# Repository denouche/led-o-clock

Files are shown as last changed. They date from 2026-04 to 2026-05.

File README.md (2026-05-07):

# Led'o'clock

> 🚧 WORK IN PROGRESS: This project is currently under active development. Files and documentation may change frequently.

Led'o'clock is a smart, connected, visual nightlight and time indicator designed to help kids understand when it's time to sleep, play, or wake up. 

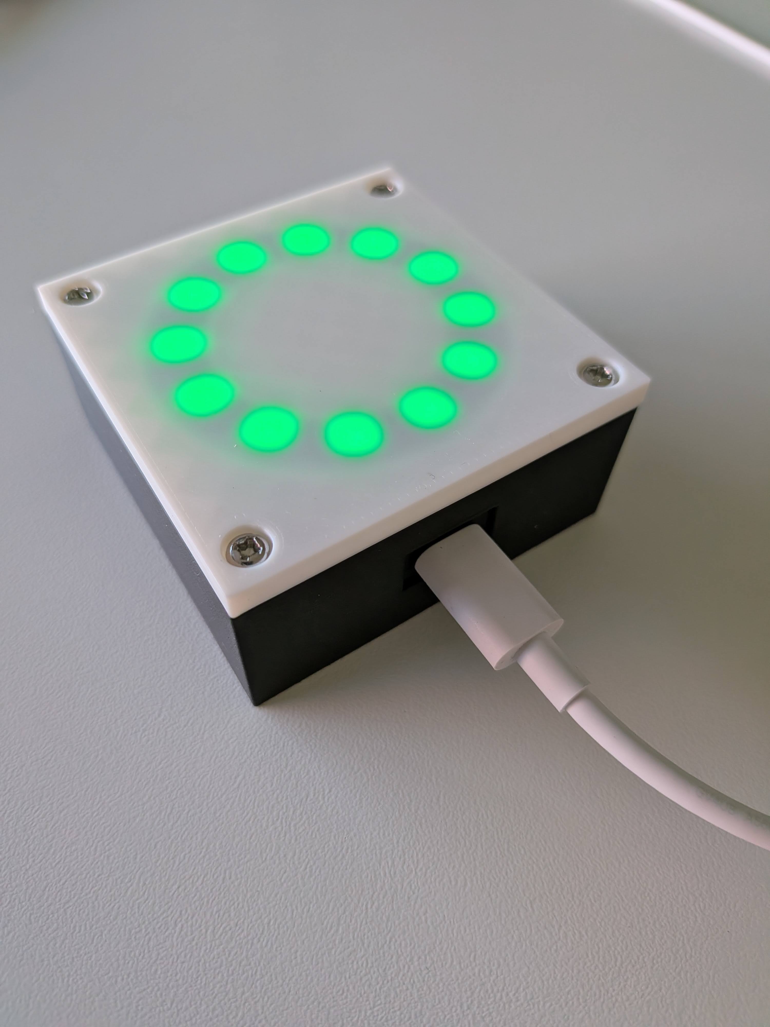
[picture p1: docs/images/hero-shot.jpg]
Led'o'clock fully assembled


This monorepo contains everything you need to build your own: the custom PCB, the 3D printable enclosure, and the ESP32 firmware.

## Usage

### LED Color Code

During normal operation, the ring displays the color defined in the active time slot of your schedule.

> Note that if no schedule is set, the ring will remain off. It's the initial state after configuring WiFi.

The LED ring also provides visual feedback for system events:

| Color | Meaning |
| :--- | :--- |
| 🔵 Light Blue | Device is booting and connecting to WiFi. |
| 🟡 Yellow | WiFi configuration mode — Access Point active. |
| 🟢 Green (×5 blinks) | WiFi connection successful. |
| 🟣 Purple | OTA firmware update in progress. |
| 🔴 Red (×5 blinks) | Factory Reset in progress. |

### Factory Reset

To reset the device to factory settings (wipes WiFi credentials and all configuration):

1. Hold the button on the back of the device for **5 seconds**.
2. The LED ring will start **blinking red** to confirm the reset is in progress.
3. The device restarts in Access Point mode, ready to be reconfigured.

## Features

* **Visual Time Tracking:** Uses a WS2812B LED ring to display specific colors based on the time of day.
* **Progressive Countdown:** LEDs turn off one by one to visually show how much time is left before the next scheduled event.
* **Custom Offline Schedules:** Define daily time slots with personalized hex colors and day-of-week customization. Once the initial time is synced via NTP at boot, the execution is 100% local and will continue to work perfectly even during internet outages.
* **Web Dashboard:** A standalone, mobile-friendly interface to configure the device on your local network.
* **REST API:** Fully controllable via HTTP endpoints for seamless integration with Home Assistant and other automation platforms.
* **OTA Firmware Updates:** Update the firmware over the air without physical access to the device.
* **Easy Setup:** Built-in captive portal for initial WiFi configuration.

## Web interface 

Here is the web dashboard served by the device:

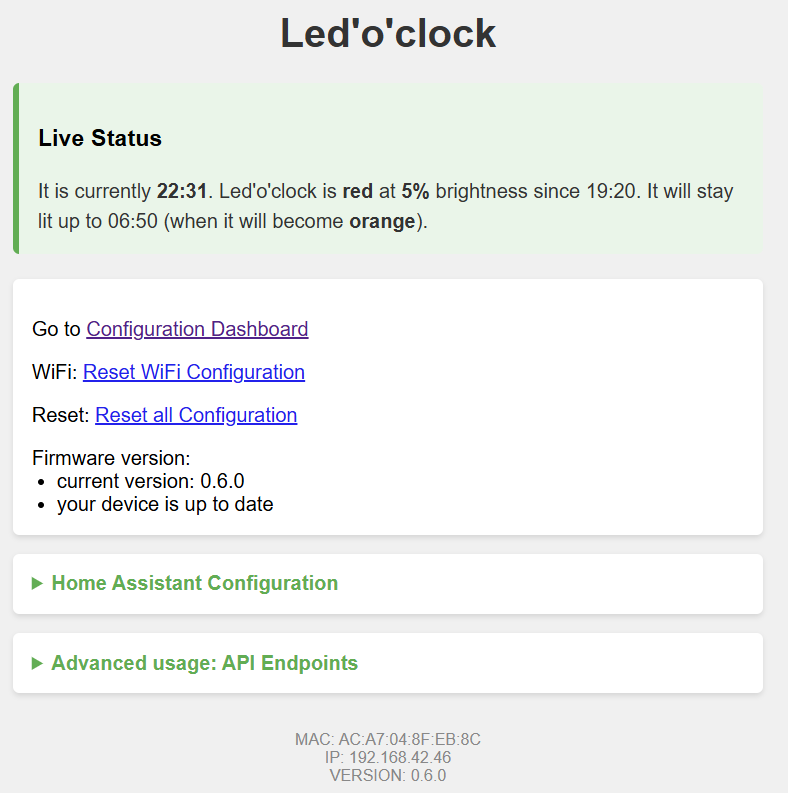
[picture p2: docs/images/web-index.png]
Web index


Here is the configuration page, where you can set the colors, time slots, and timezone:

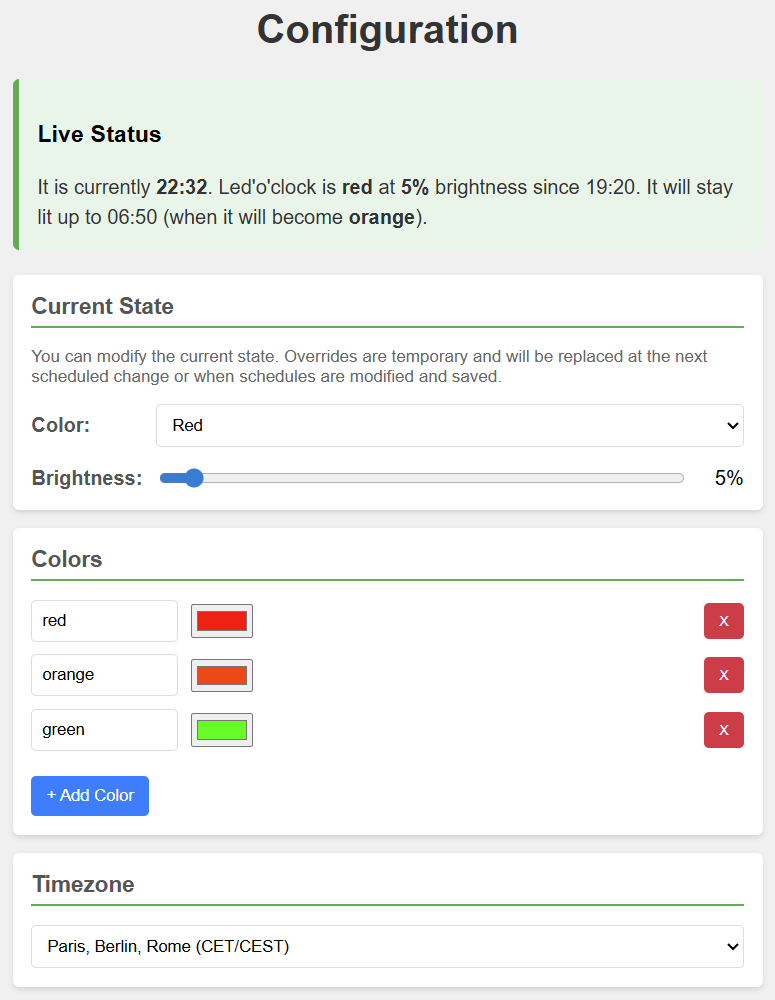
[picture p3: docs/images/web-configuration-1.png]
Web configuration


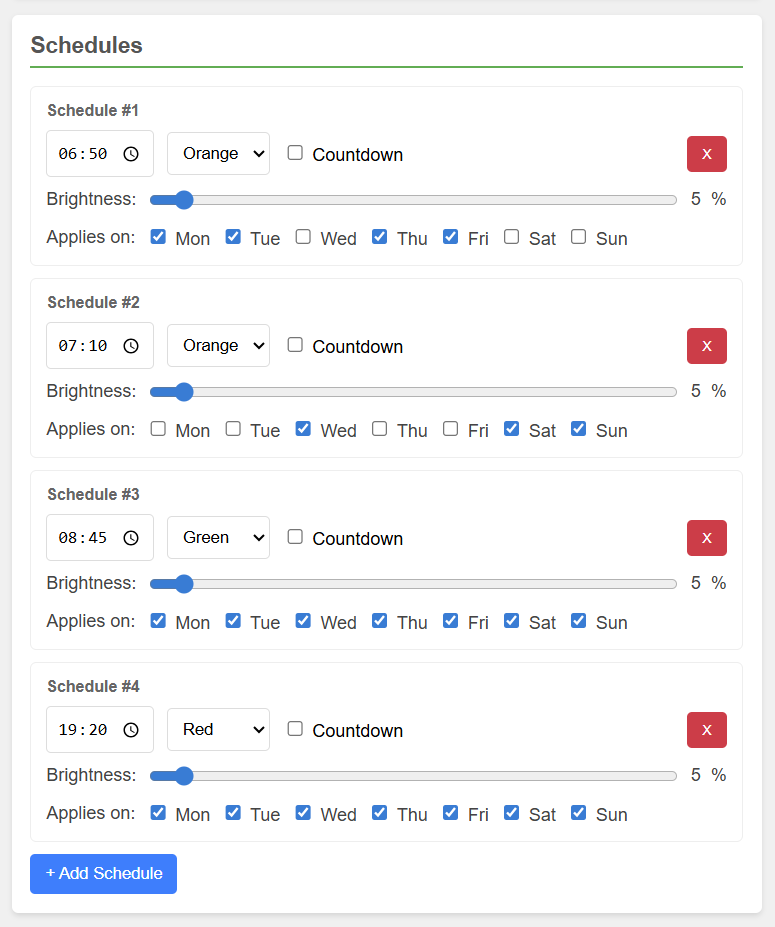
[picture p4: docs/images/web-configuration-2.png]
Web configuration


## Getting Started

The project is split into three main directories. Check the `README.md` inside each folder for specific instructions:

1. **`/pcb`**: KiCad schematics files to manufacture the board (designed around the ESP32-C3).
2. **`/enclosure`**: FreeCAD source file and ready-to-print STL files for the case.
3. **`/firmware`**: PlatformIO project containing the C++ source code. 

## License

**CC BY-NC-SA 4.0** (Creative Commons Attribution-NonCommercial-ShareAlike 4.0)

You are free to build, use, and modify this project for **personal use only**. 
You may **not** sell the source code, hardware files, 3D models, or the physical device itself. 
If you remix, adapt, or build upon the material, you must distribute your contributions under the **same license** as the original, credit the original author (Antoine Leveugle), and link back to this repository.

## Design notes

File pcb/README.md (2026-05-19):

# Led'o'clock PCB

> 🚧 WORK IN PROGRESS: The v3.2 PCB design is currently being finalized. Files and documentation may change frequently.
> This v3.2 version will not require any manual soldering, as all components (including the USB-C module) are now designed for SMD assembly by JLCPCB. The documentation below still applies to the previous v3.0 version which requires some manual soldering.

This folder contains the KiCad design files, manufacturing data, and documentation for the Led'o'clock custom board.

The board is built around the **ESP32-C3** microcontroller. To optimize production costs, the surface-mount devices (SMD) are designed to be assembled by JLCPCB, but **some manual soldering is required** to complete the board.

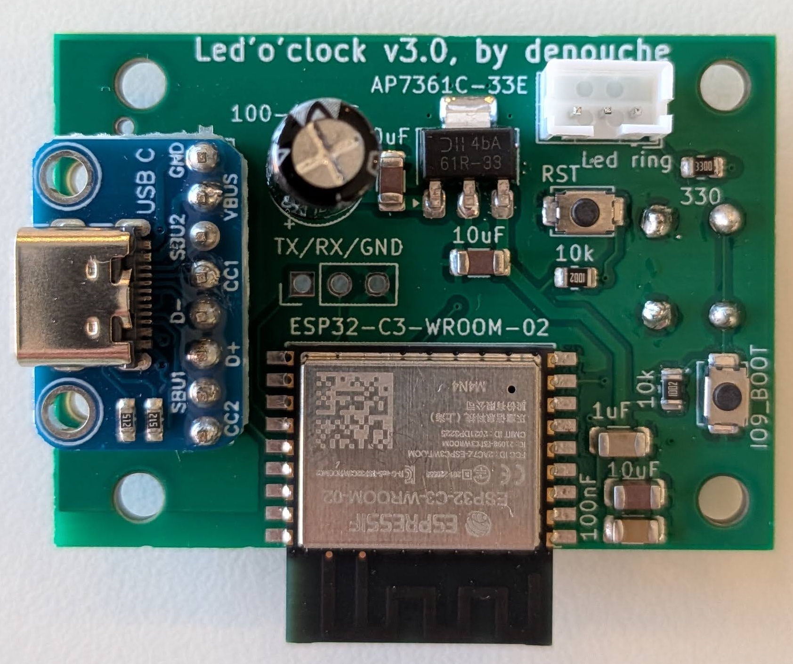
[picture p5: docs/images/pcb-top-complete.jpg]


## 1. Manufacturing (JLCPCB PCBA)

The PCB is designed for partial assembly (SMD only) using JLCPCB's "Basic" parts.

1. Go to JLCPCB and upload the Gerber archive: `jlcpcb/production_files/GERBER-led-o-clock.zip`.
2. Enable the **PCB Assembly (PCBA)** option (Top side only).
3. Upload the Bill of Materials: `jlcpcb/production_files/BOM-led-o-clock.csv`.
4. Upload the Pick and Place file: `jlcpcb/production_files/CPL-led-o-clock.csv`.

*Note: Although the through-hole components listed below have footprints and LCSC part numbers in the KiCad project, they were intentionally excluded from the automated assembly files to minimize factory setup fees.*

Here is the resulting board you should receive from the factory, with all SMD components pre-soldered:

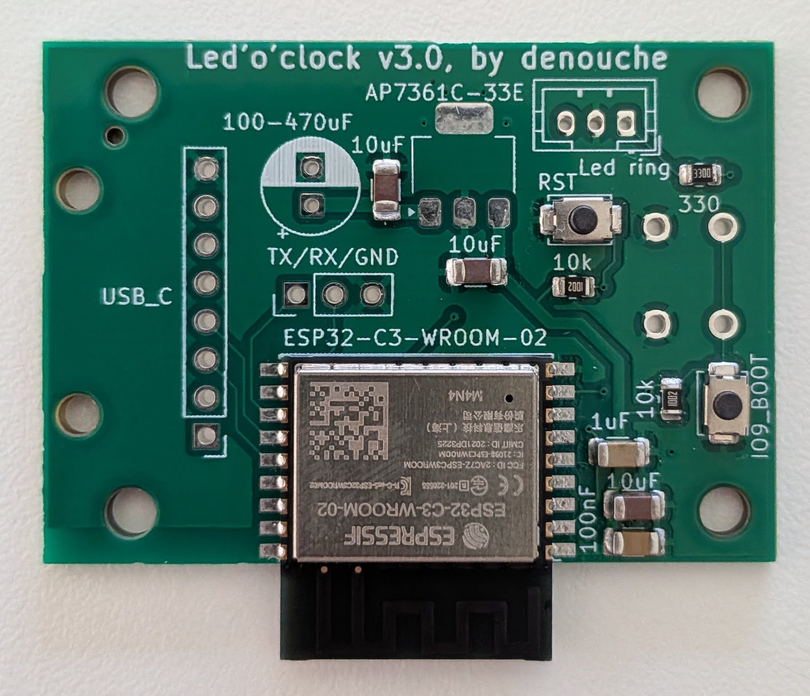
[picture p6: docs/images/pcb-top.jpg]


## 2. Required Manual Soldering

Once you receive the partially assembled boards from the factory, you must manually solder the following through-hole components:

* **USB-C Module (6-pin):** A standard 6-pin USB-C female breakout board.
  ⚠️ **IMPORTANT:** The module **must** feature two **5.1kΩ pull-down resistors** on the CC1 and CC2 pins. Without these resistors, the device will NOT work with USB-C to USB-C cables or PD chargers.

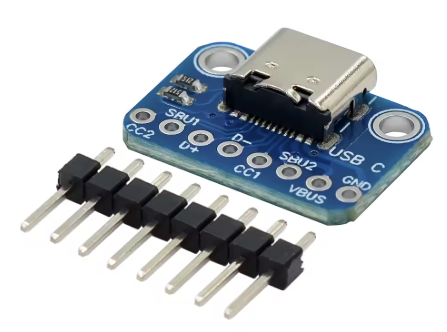
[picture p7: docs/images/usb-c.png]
USB-C Module with 5.1k resistors
  

* **JST PH 2.0 Connector (3-pin):** A horizontal female connector to plug in the LED ring.
* **Capacitor:** A 330µF electrolytic capacitor for power smoothing. *(Pay attention to the polarity!)*
* **Tactile Switch:** A 6x6mm push button. **Important:** This component must be soldered on the **BOTTOM side** of the PCB so it aligns properly with the 3D printed enclosure hole.

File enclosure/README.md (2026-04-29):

# Led'o'clock Enclosure

This folder contains the 3D printable enclosure for the Led'o'clock project. The case is designed to house the ESP32-C3 module and a 12-LED WS2812B ring, with a clean **64 × 64 mm** square footprint.

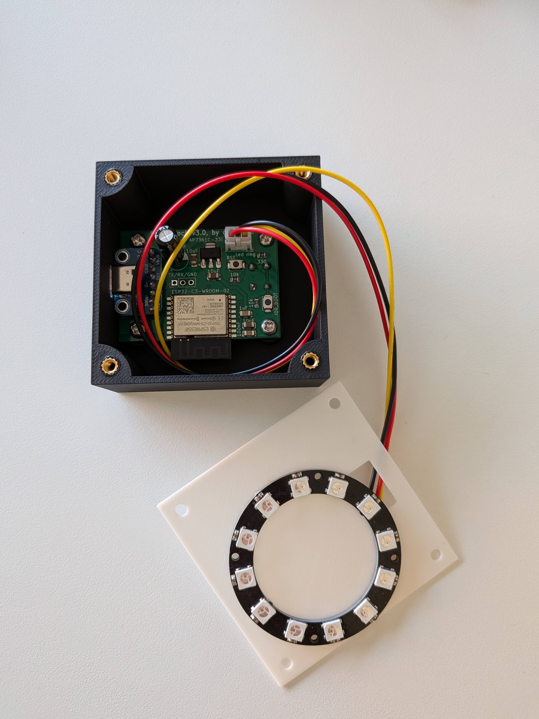
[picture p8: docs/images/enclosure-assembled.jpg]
Led'o'clock fully assembled


## Files

| File | Description |
| :--- | :--- |
| `ledoclock.FCStd` | FreeCAD source file — open this to modify the design. |
| `ledoclock.3mf` | Bambu Studio project file — ready to slice, includes print settings. |
| `ledoclock-box bottom.stl` | Main body: houses the PCB and the ESP32-C3. |
| `ledoclock-lid.stl` | Top lid: snaps onto the body, houses the LED ring and acts as a light diffuser frame. |
| `ledoclock-ring retainer.stl` | Thin ring retainer: keeps the LED ring flush inside the lid cavity. |

## Customization (Parametric Design)

The **`ledoclock.FCStd`** file is fully parametric. If you need to resize the box or use a different LED ring (e.g., 16 or 24 LEDs):

1. Open the file in **FreeCAD**.
2. Locate the **Spreadsheet** in the tree view.
3. Modify the aliases dimensions as you want.
4. The 3D model will update automatically.
5. Re-export the parts as STL for printing.

## Dimensions (Default)

| Part | W × D × H |
| :--- | :--- |
| Box bottom | 64 × 64 × 25 mm |
| Lid | 64 × 64 × 4 mm |
| Ring retainer | 64 × 64 × 0.8 mm |
| **Assembled** | **64 × 64 × 29 mm** |

## Recommended Print Settings

The `.3mf` file embeds all settings below and was validated on a **Bambu Lab P1S**.

| Parameter | Value |
| :--- | :--- |
| Infill | 15 % — Gyroid |
| Supports | **Lid only** — Tree (Auto) |

> Any standard FDM printer with a **≥ 180 × 180 mm** bed can print all three parts. Non-Bambu users should reproduce the settings above in their own slicer.

## Assembly Instructions

### 1. Hot-Melt Inserts
Once the `Box bottom` is printed, you need to embed brass threaded inserts into the mounting standoffs using a soldering iron. This allows the PCB to be securely mounted to the case.

* **Required hardware:** 8× `M3` brass threaded inserts.

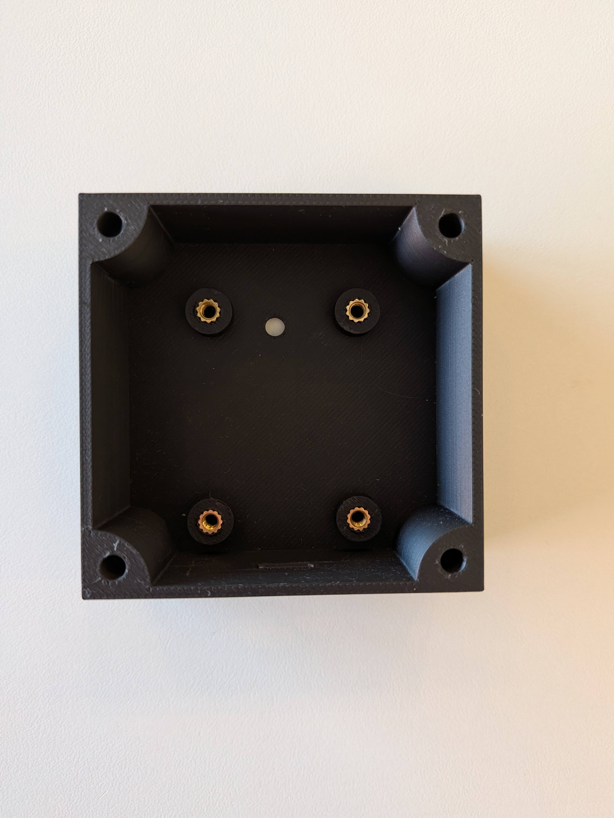
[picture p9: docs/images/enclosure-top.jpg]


### 2. Final Assembly
1. Seat the assembled PCB into the box bottom and secure it with 4× `M3` screws.
2. Insert the 12-LED WS2812B ring into the top `Lid`.
3. Place the `Ring retainer` behind the LED ring to keep it perfectly flush against the diffuser.
4. Plug the LED ring's cable into the JST connector on the PCB.
5. Snap the `Lid` onto the `Box bottom`.

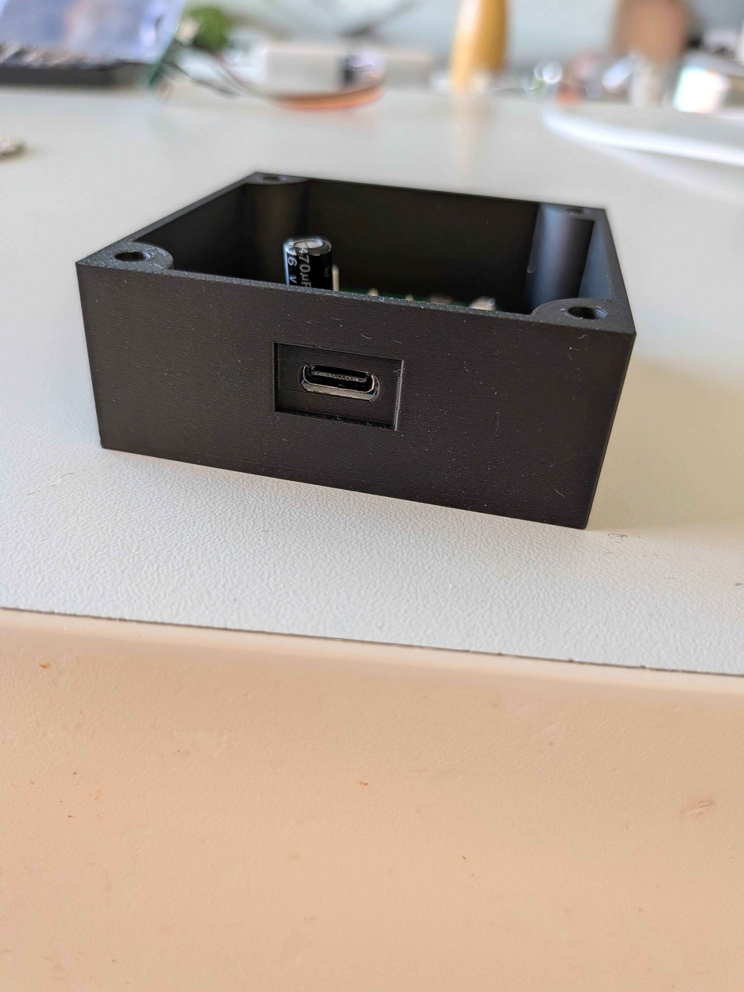
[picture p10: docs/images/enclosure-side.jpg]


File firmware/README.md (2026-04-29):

# Led'o'clock Firmware

This folder contains the ESP32-C3 source code built with **PlatformIO**. It manages the WiFi portal, NTP synchronization, and the LED ring animation logic.

## Key Features

* **Built-in Web Server**: Serves a responsive UI stored entirely in Flash memory (embedded via `board_build.embed_txtfiles`).
* **RESTful API**: Allows full control of the device through simple HTTP requests.
* **mDNS Support**: Discovers the device on the local network as `ledoclock-<mac>.local` (unique per device).
* **7-Day Scheduler**: Robust time-keeping logic that handles weekly routines and internet outages.
* **NTP Sync**: Automatically fetches time at boot and applies the configured POSIX timezone.
* **OTA Updates**: Firmware can be updated over-the-air.
* **WiFi Mesh Roaming**: Automatically connects to the strongest access point in a mesh network.

## REST API Endpoints

The firmware exposes the following endpoints for automation:

| Endpoint | Method | Description |
| :--- | :--- | :--- |
| `/status` | `GET` | Returns a JSON object with version, time, brightness, colors, timezone, and schedules. |
| `/set_brightness?value=X` | `GET` | Sets the ring brightness (0 to 100). |
| `/set_color?value=NAME` | `GET` | Manually forces a color (e.g., `red`, `green`, `off`). |
| `/set_timezone?value=TZ` | `GET` | Updates the device timezone (POSIX string, e.g., `CET-1CEST,M3.5.0,M10.5.0/3`). |
| `/colors` | `POST` | Updates the hex definitions of custom colors (JSON body). |
| `/schedule` | `POST` | Updates the full weekly schedule (JSON body). |
| `/firmware_check` | `GET` | Checks GitHub API for updates and returns version info (JSON). |
| `/firmware_update` | `POST` | Triggers the OTA firmware download and flash process. |
| `/reset_wifi` | `GET` | Wipes WiFi credentials and restarts in Access Point mode. |
| `/reset` | `GET` | Wipes all settings (WiFi + saved configuration) and restarts in Access Point mode. |
| `/ping` | `GET` | Returns `{"status":"pong"}` — useful for connectivity checks. |

## Hardware Mapping

* **GPIO 3**: WS2812B Data Line (connected to the LED ring).
* **GPIO 9**: Multi-purpose button (built-in BOOT button — hold at boot for **Flash Mode** / Long press (5 s) during runtime for **Factory Reset**).

## LED Status Signals

The ring provides visual feedback for system events:

| Color | Meaning |
| :--- | :--- |
| 🔵 Light Blue | Device is booting and attempting to connect to WiFi. |
| 🟡 Yellow | WiFi Configuration mode — Access Point is active. |
| 🟢 Green (×5 blinks) | WiFi connection successful. |
| 🟣 Purple | Firmware OTA update in progress. |
| 🔴 Red (×5 blinks) | Factory Reset in progress. |

## Installation

### Prerequisites

* **PlatformIO IDE** (VS Code extension recommended).
* **ESP32-C3** module with native USB (no USB-to-Serial adapter required).

### Setup & Upload

1. Open this folder in VS Code/PlatformIO.
2. The `platformio.ini` is already configured for a 4MB flash module using the **`min_spiffs`** partition scheme (LittleFS).
3. Connect your ESP32-C3 via USB.
4. Run the **Upload** task.

### Debugging

The Serial Monitor speed is set to `115200` baud.

### Development Notes

The UI is built using vanilla JavaScript and CSS, embedded in C++ as binary data via the `board_build.embed_txtfiles` PlatformIO directive. It uses asynchronous `fetch` calls to interact with the API endpoints listed above, ensuring a smooth user experience.

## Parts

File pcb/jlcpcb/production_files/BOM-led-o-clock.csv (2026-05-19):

Comment | Designator | Footprint | LCSC | Quantity
100nF | C3 | C_1206_3216Metric | C24497 | 1
100uF | C11 | CP_Elec_6.3x5.4 | C2887276 | 1
10k | R2,R3 | R_0805_2012Metric | C17414 | 2
10uF | C2,C4,C6 | C_1206_3216Metric | C13585 | 3
1uF | C5 | C_1206_3216Metric | C1848 | 1
330 | R4 | R_0805_2012Metric | C17630 | 1
5.1k | R1,R5 | R_0805_2012Metric | C27834 | 2
AP7361C-33E | U1 | SOT-223-3_TabPin2 | C500795 | 1
ESP32-C3-WROOM-02 | U2 | ESP32-C3-WROOM-02 | C2934560 | 1
FerriteBead_Small | FB1 | L_0603_1608Metric | C14709 | 1
IO9_BOOT | SW3 | SW_SPST_TS-1088-xR020 | C720477 | 1
Led ring | J4 | JST_PH_S3B-PH-K_1x03_P2.00mm_Horizontal | C157929 | 1
RST | SW4 | SW_SPST_TS-1088-xR020 | C720477 | 1
USB_C_Receptacle_USB2.0_16P | J1 | USB_C_Receptacle_HRO_TYPE-C-31-M-12 | C165948 | 1

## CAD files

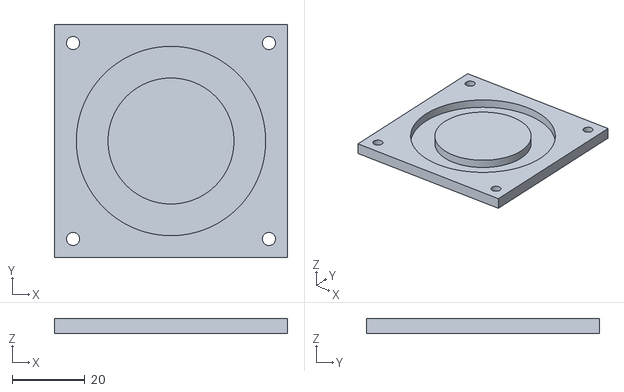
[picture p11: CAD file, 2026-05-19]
enclosure/ledoclock-lid.stl
64.0 x 64.0 x 4.00

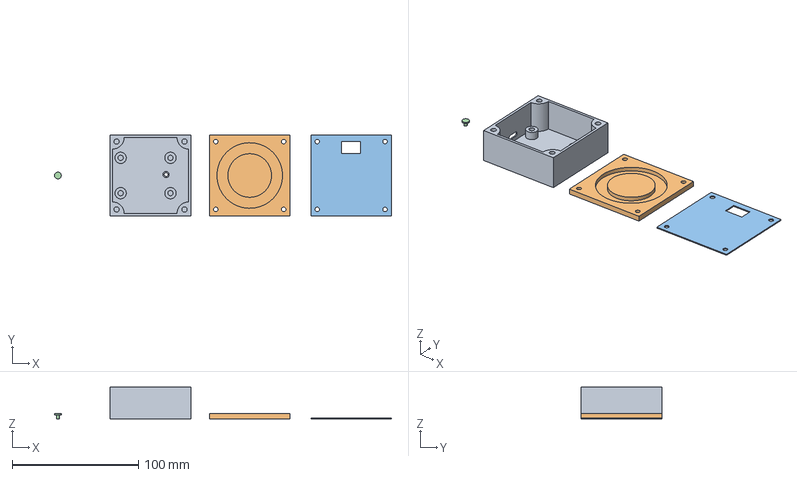
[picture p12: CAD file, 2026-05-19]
enclosure/ledoclock.FCStd
267.2 x 64.0 x 25.0 mm
box bottom
lid
ring retainer
reset button

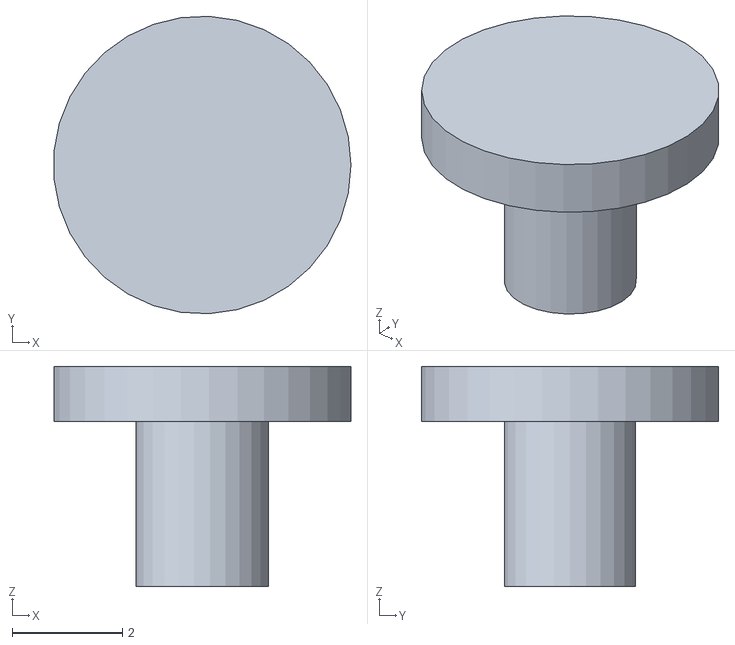
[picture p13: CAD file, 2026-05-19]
enclosure/ledoclock-reset button.stl
5.39 x 5.39 x 4.00

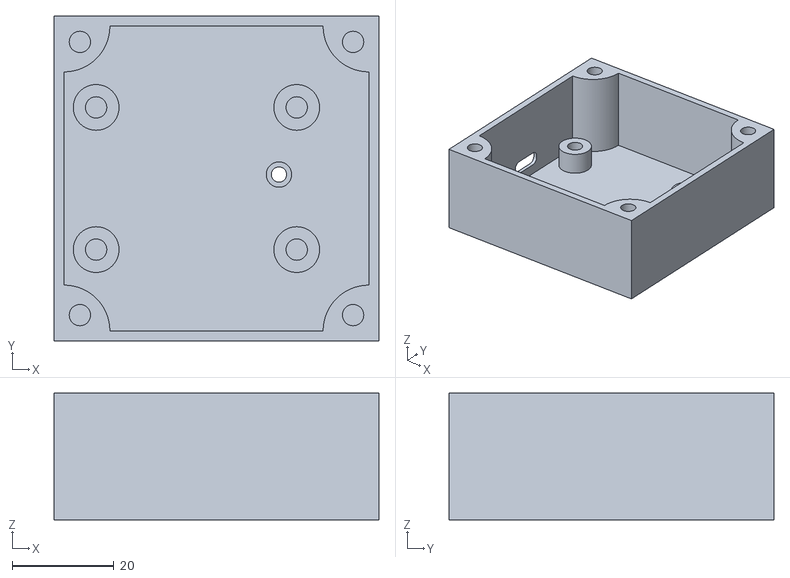
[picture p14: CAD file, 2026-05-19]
enclosure/ledoclock-box bottom v3.1.stl
64.0 x 64.0 x 25.0

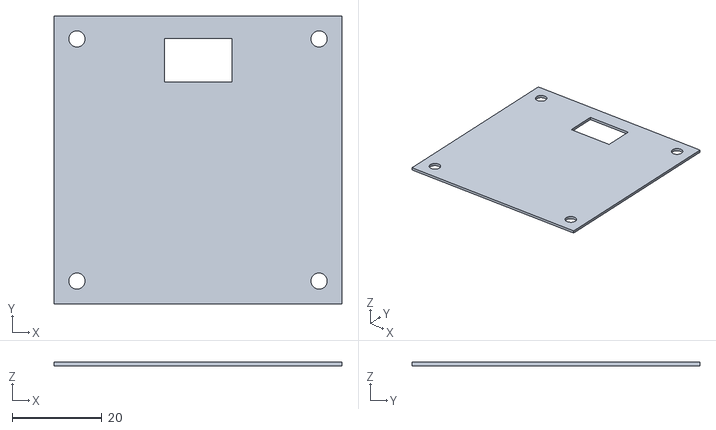
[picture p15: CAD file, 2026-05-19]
enclosure/ledoclock-ring retainer.stl
64.0 x 64.0 x 0.8

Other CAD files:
enclosure/ledoclock-box bottom v3.0.stl
enclosure/ledoclock.3mf

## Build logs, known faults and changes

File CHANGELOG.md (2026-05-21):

# [1.2.0](https://github.com/denouche/led-o-clock/compare/firmware-1.1.0...firmware-1.2.0) (2026-05-21)

### Bug Fixes

* **pcb:** improve button placement and add QR code ([9fd4abb](https://github.com/denouche/led-o-clock/commit/9fd4abb37743e466d26927f49193d1b6cf61663b))

### Features

* **enclosure:** work on v3.1 enclosure ([44e2d0d](https://github.com/denouche/led-o-clock/commit/44e2d0d0b37f5188ccae702cb5005594614ab368))
* **firmware:** add GET /set_leds_on endpoint ([#8](https://github.com/denouche/led-o-clock/issues/8)) ([9e0ffce](https://github.com/denouche/led-o-clock/commit/9e0ffcedce582659c4645045b0127e3a8afb4af7))
* **pcb:** work on v3.2 ([9e711f4](https://github.com/denouche/led-o-clock/commit/9e711f4f5bbf9757de8afd5cb196e56171b1693e))

# [1.1.0](https://github.com/denouche/led-o-clock/compare/firmware-1.0.0...firmware-1.1.0) (2026-04-29)

### Bug Fixes

* **pcb:** move jst connector on the top ([#6](https://github.com/denouche/led-o-clock/issues/6)) ([a4a3ec3](https://github.com/denouche/led-o-clock/commit/a4a3ec3f5f545fc882d85de9f8cf33023da9cf9b))

### Features

* **firmware:** use gh pages manifest for OTA update ([#7](https://github.com/denouche/led-o-clock/issues/7)) ([9efd22f](https://github.com/denouche/led-o-clock/commit/9efd22f0976dd2a50e7f2274a3ea8f6e5961b008))

# 1.0.0 (2026-04-29)

### Bug Fixes

* **firmware:** add missing firmware upgrade documentation on index ([eac0821](https://github.com/denouche/led-o-clock/commit/eac082140b3520e5f0013a624b8bb06c9eb9eabd))
* **firmware:** factory reset feedback is now a red blink 5 times ([#1](https://github.com/denouche/led-o-clock/issues/1)) ([de2a2db](https://github.com/denouche/led-o-clock/commit/de2a2dbc27fe11c1482be1cc582173bf9838cc6d))
* **firmware:** fix documentation ([69edb70](https://github.com/denouche/led-o-clock/commit/69edb7068c953dc65c9f04d9776cdc7684711e32))
* **firmware:** improve success toast when saving configuration ([ac17b20](https://github.com/denouche/led-o-clock/commit/ac17b20a670e8e572bbc93c68a41e2f8bcd23e4a))
* fix release firmware publish ([7784a4f](https://github.com/denouche/led-o-clock/commit/7784a4fffaed6dbe78a8b9fdbee2c75096bf966c))
* separate releases per module ([3536034](https://github.com/denouche/led-o-clock/commit/3536034dbf100b632d2b42d679255ac8e0b18b28))

### Features

* add ci workflows ([776b9b9](https://github.com/denouche/led-o-clock/commit/776b9b9ad46168cb7f1f9bd4b5ebaec1965b2cb0))
* add firmware ([9dd80d4](https://github.com/denouche/led-o-clock/commit/9dd80d4eb3a6f75572a6693284132ddf853d2462))
* add pcb folder and work on readme ([51abcd6](https://github.com/denouche/led-o-clock/commit/51abcd60a1240a7f589b55eeadc327e77937034b))
* change firmware upgrade endpoint from GET to POST with toast feedback ([#4](https://github.com/denouche/led-o-clock/issues/4)) ([71c531c](https://github.com/denouche/led-o-clock/commit/71c531c76bc877f158fbf49b6a1576a7a53bc879))
* **enclosure:** add enclosure files ([ff69254](https://github.com/denouche/led-o-clock/commit/ff6925458fe482433d2bfd948a1ecf59863dcd38))
* **firmware:** add OTA update support ([87618de](https://github.com/denouche/led-o-clock/commit/87618deee0467314c9d811fd38103e1c16b057e7))
* **firmware:** allow to customize brightness for each schedule ([#3](https://github.com/denouche/led-o-clock/issues/3)) ([9e97505](https://github.com/denouche/led-o-clock/commit/9e97505a7ca96110615698fc4b5895fbce906067))
* **firmware:** display current and available firmware versions on web UI ([#5](https://github.com/denouche/led-o-clock/issues/5)) ([de0d7cf](https://github.com/denouche/led-o-clock/commit/de0d7cf7bd49da8f819df5712bd062cbf80a3978))

# [0.7.0](https://github.com/denouche/led-o-clock/compare/0.6.0...0.7.0) (2026-04-29)

### Features

* add pcb folder and work on readme ([51abcd6](https://github.com/denouche/led-o-clock/commit/51abcd60a1240a7f589b55eeadc327e77937034b))

# [0.6.0](https://github.com/denouche/led-o-clock/compare/0.5.0...0.6.0) (2026-04-12)

### Features

* **firmware:** display current and available firmware versions on web UI ([#5](https://github.com/denouche/led-o-clock/issues/5)) ([de0d7cf](https://github.com/denouche/led-o-clock/commit/de0d7cf7bd49da8f819df5712bd062cbf80a3978))

# [0.5.0](https://github.com/denouche/led-o-clock/compare/0.4.0...0.5.0) (2026-04-12)

### Features

* change firmware upgrade endpoint from GET to POST with toast feedback ([#4](https://github.com/denouche/led-o-clock/issues/4)) ([71c531c](https://github.com/denouche/led-o-clock/commit/71c531c76bc877f158fbf49b6a1576a7a53bc879))

# [0.4.0](https://github.com/denouche/led-o-clock/compare/0.3.1...0.4.0) (2026-04-12)

### Features

* **firmware:** allow to customize brightness for each schedule ([#3](https://github.com/denouche/led-o-clock/issues/3)) ([9e97505](https://github.com/denouche/led-o-clock/commit/9e97505a7ca96110615698fc4b5895fbce906067))

## [0.3.1](https://github.com/denouche/led-o-clock/compare/0.3.0...0.3.1) (2026-04-12)

### Bug Fixes

* **firmware:** factory reset feedback is now a red blink 5 times ([#1](https://github.com/denouche/led-o-clock/issues/1)) ([de2a2db](https://github.com/denouche/led-o-clock/commit/de2a2dbc27fe11c1482be1cc582173bf9838cc6d))

# [0.3.0](https://github.com/denouche/led-o-clock/compare/0.2.1...0.3.0) (2026-04-11)

### Features

* **enclosure:** add enclosure files ([ff69254](https://github.com/denouche/led-o-clock/commit/ff6925458fe482433d2bfd948a1ecf59863dcd38))

## [0.2.1](https://github.com/denouche/led-o-clock/compare/0.2.0...0.2.1) (2026-04-11)

### Bug Fixes

* **firmware:** add missing firmware upgrade documentation on index ([eac0821](https://github.com/denouche/led-o-clock/commit/eac082140b3520e5f0013a624b8bb06c9eb9eabd))

# [0.2.0](https://github.com/denouche/led-o-clock/compare/0.1.1...0.2.0) (2026-04-11)

### Features

* **firmware:** add OTA update support ([87618de](https://github.com/denouche/led-o-clock/commit/87618deee0467314c9d811fd38103e1c16b057e7))

## [0.1.1](https://github.com/denouche/led-o-clock/compare/0.1.0...0.1.1) (2026-04-11)

### Bug Fixes

* **firmware:** improve success toast when saving configuration ([ac17b20](https://github.com/denouche/led-o-clock/commit/ac17b20a670e8e572bbc93c68a41e2f8bcd23e4a))
* fix release firmware publish ([7784a4f](https://github.com/denouche/led-o-clock/commit/7784a4fffaed6dbe78a8b9fdbee2c75096bf966c))

# [0.1.0](https://github.com/denouche/led-o-clock/compare/0.0.1...0.1.0) (2026-04-11)

### Features

* add ci workflows ([776b9b9](https://github.com/denouche/led-o-clock/commit/776b9b9ad46168cb7f1f9bd4b5ebaec1965b2cb0))

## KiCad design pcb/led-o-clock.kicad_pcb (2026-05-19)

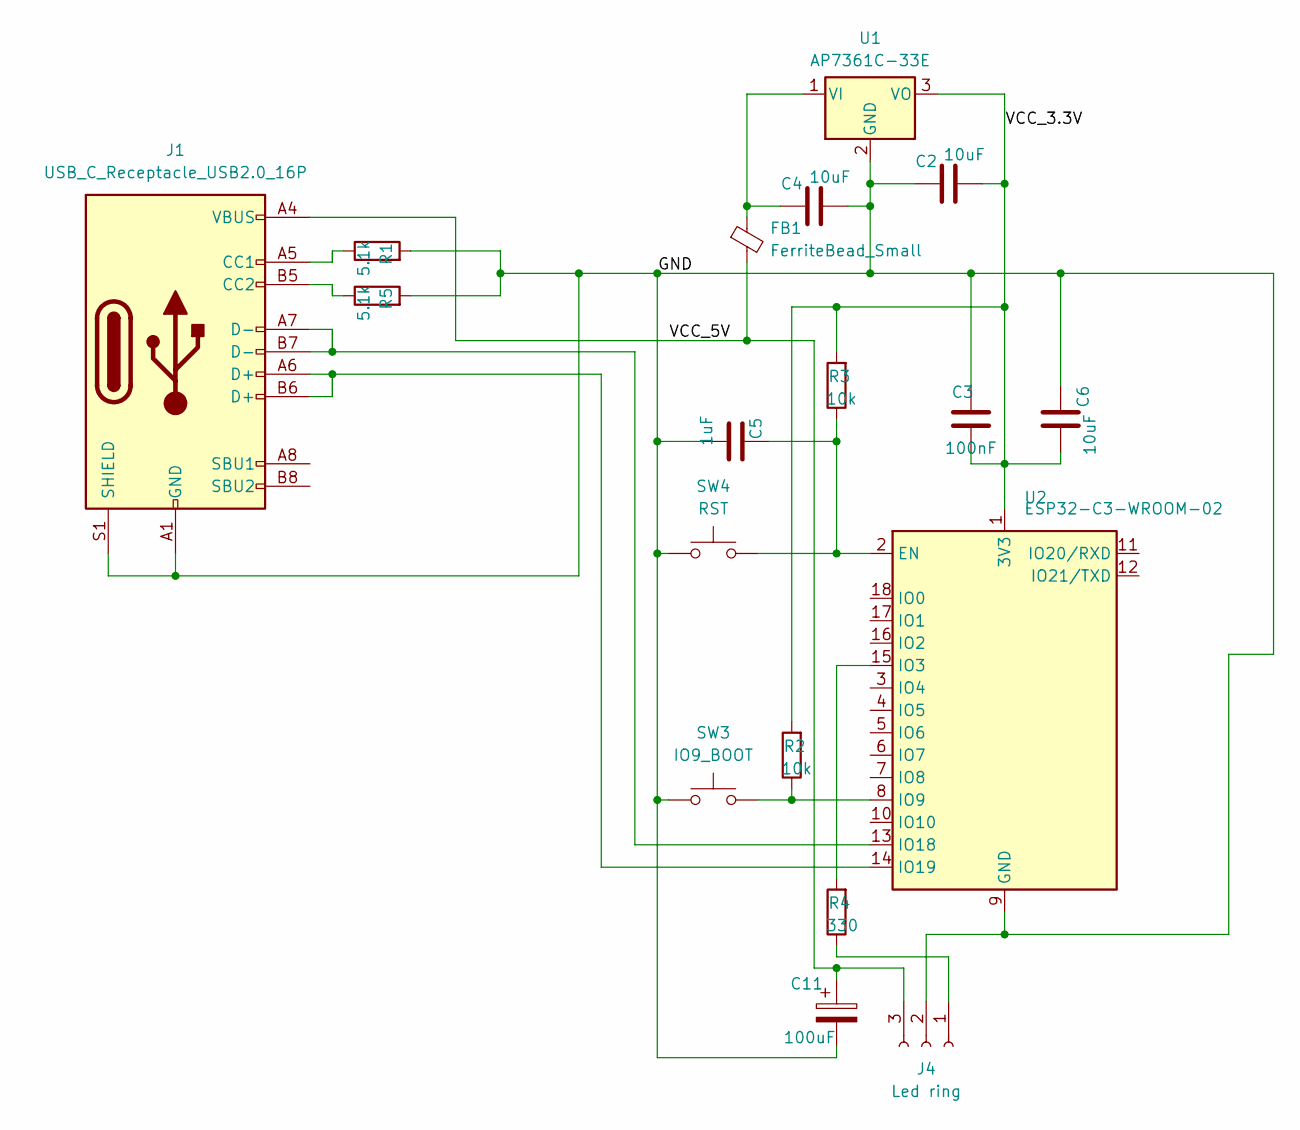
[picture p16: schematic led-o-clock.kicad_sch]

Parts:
C2, C4, C6: 10uF; C_1206_3216Metric; LCSC PN C13585
C3: 100nF; C_1206_3216Metric; LCSC PN C24497
C5: 1uF; C_1206_3216Metric; LCSC PN C1848
C11: 100uF; CP_Elec_6.3x5.4; LCSC PN C2887276
FB1: FerriteBead_Small; L_0603_1608Metric; LCSC PN C14709
J1: USB_C_Receptacle_USB2.0_16P; USB_C_Receptacle_HRO_TYPE-C-31-M-12; LCSC PN C165948
J4: Led ring; JST_PH_S3B-PH-K_1x03_P2.00mm_Horizontal; LCSC PN C157929
R1, R5: 5.1k; R_0805_2012Metric; LCSC PN C27834
R2, R3: 10k; R_0805_2012Metric; LCSC PN C17414
R4: 330; R_0805_2012Metric; LCSC PN C17630
SW3: IO9_BOOT; SW_SPST_TS-1088-xR020; LCSC PN C720477
SW4: RST; SW_SPST_TS-1088-xR020; LCSC PN C720477
U1: AP7361C-33E; SOT-223-3_TabPin2; LCSC PN C500795
U2: ESP32-C3-WROOM-02; LCSC PN C2934560

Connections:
/GND: C2.2, C3.1, C4.1, C5.2, C6.2, C11.2, J1.A1 (GND), J1.A12 (GND), J1.B1 (GND), J1.B12 (GND), J1.S1 (SHIELD), J4.2, R1.2, R5.2, SW3.1, SW4.1, U1.2 (GND), U2.9 (GND), U2.19 (GND)
/VCC_3.3V: C2.1, C3.2, C6.1, R2.2, R3.2, U1.3 (VO), U2.1 (3V3)
/VCC_5V: C11.1, FB1.2, J1.A4 (VBUS), J1.A9 (VBUS), J1.B4 (VBUS), J1.B9 (VBUS), J4.3
unnamed: J1.A5 (CC1), R1.1
unnamed: J1.B5 (CC2), R5.1
unnamed: J4.1, R4.1
unnamed: C4.2, FB1.1, U1.1 (VI)
unnamed: C5.1, R3.1, SW4.2, U2.2 (EN)
unnamed: R4.2, U2.15 (IO3)
unnamed: R2.1, SW3.2, U2.8 (IO9)
unnamed: J1.A7 (D-), J1.B7 (D-), U2.13 (IO18)
unnamed: J1.A6 (D+), J1.B6 (D+), U2.14 (IO19)

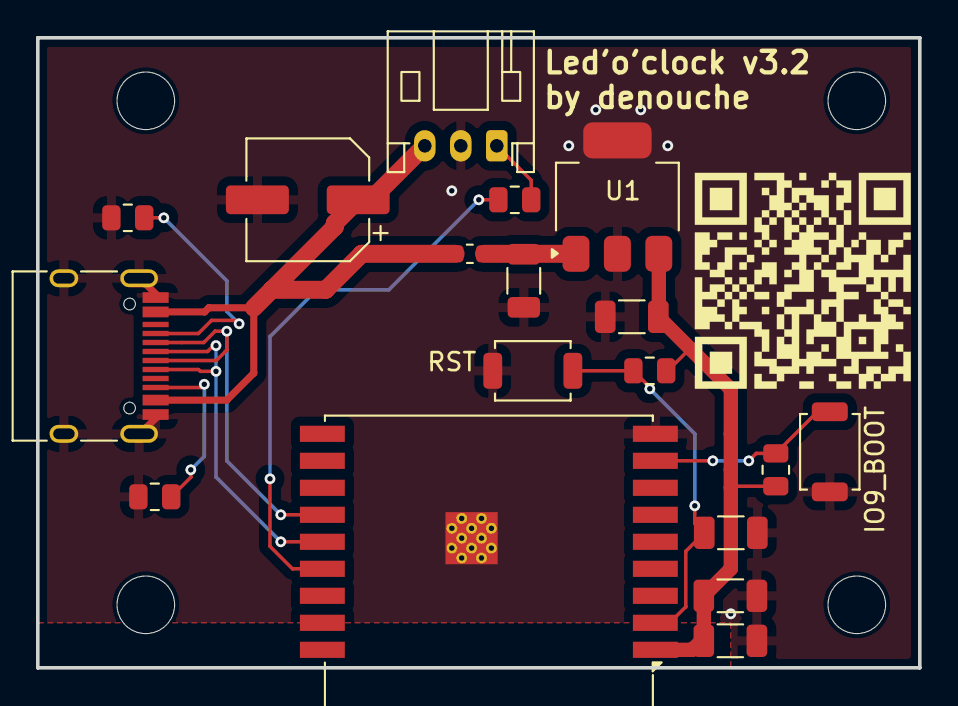
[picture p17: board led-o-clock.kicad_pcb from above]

Board: 2 copper layers, 49.0 x 35.0 mm, 18 parts (0 on the bottom side), 12 nets.

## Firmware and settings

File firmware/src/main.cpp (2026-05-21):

/**
 * Project: Led'o'clock
 * Hardware: ESP32-C3-WROOM-02
 * Display: WS2812B LED Ring on GPIO2
 * Author: Antoine Leveugle
 * 
 * * Note: GPIO9 button is used for both Flash Mode (at boot) and WiFi Reset (long press during runtime).
 * 
 * * LED Status Signals:
 * - Light Blue: System booting and attempting to connect to WiFi.
 * - Yellow: WiFi Configuration mode (Access Point active).
 * - Green (Blinks 5 times): WiFi connection successful.
 * - Purple: Firmware update in progress.
 * - Red (Blinks 5 times): Factory Reset in progress.
 */

#include <Adafruit_NeoPixel.h>
#include <Arduino.h>
#include <ArduinoJson.h>
#include <ESPmDNS.h>
#include <WiFi.h>
#include <esp_wifi.h>
#include <LittleFS.h>
#include <time.h>
#include <WiFiManager.h>

#include "config.h"
#include "storage.h"
#include "led_control.h"
#include "api_handlers.h"
#include "web/wifi_manager_html.h"

#ifndef BUILD_TAG
    #define BUILD_TAG "build-dev"
#endif
const char* FIRMWARE_VERSION = (BUILD_TAG[0] == '\0') ? "dev-build" : BUILD_TAG;

// --- State Management ---
Schedule schedules[MAX_SCHEDULES];
int scheduleCount = 0;

ColorDef definedColors[MAX_COLORS];
int definedColorCount = 0;

int globalBrightness = 128;
String currentColorMode = "off";
String currentTimezone = "CET-1CEST,M3.5.0,M10.5.0/3"; // Default timezone
int currentLedsOn = NUM_LEDS; // Track how many LEDs are currently lit to avoid redundant updates

/**
 * Configure WiFi Roaming for Mesh stability (ESP32 Specific)
 */
void configureWiFiRoaming() {
    wifi_config_t conf;
    esp_wifi_get_config(WIFI_IF_STA, &conf);

    // Connect to the strongest AP in the mesh
    conf.sta.scan_method = WIFI_ALL_CHANNEL_SCAN;
    conf.sta.sort_method = WIFI_CONNECT_AP_BY_SIGNAL;
    
    // Threshold to trigger search for a better AP (in dBm)
    conf.sta.threshold.rssi = -75; 

    esp_wifi_set_config(WIFI_IF_STA, &conf);
}

void setup() {
    Serial.begin(115200);
    delay(500); // Allow time for Native USB Serial to initialize

    Serial.println();
    Serial.println();
    Serial.println("================================");
    Serial.println("================================");
    Serial.println("STARTING Led'o'clock");
    Serial.println("================================");
    Serial.println("================================");

    // Hardware Setup
    initLedRing();
    pinMode(PIN_BUTTON, INPUT_PULLUP);
    
    setBrightness(1);
    setRingRgb(0, 255, 255); // light blue to indicate device is booting and attempting WiFi connection

    // --- Filesystem Initialization ---
    if (!LittleFS.begin(true)) {
        Serial.println("LittleFS fatal error: Mount and format failed.");
    }

    Serial.println("Connecting to WiFi...");
    
    // Networking
    // For mDNS and network identity
    String chipId = getUniqueChipId();
    String hostname = "ledoclock-" + chipId;

    WiFi.setHostname(hostname.c_str());
    WiFiManager wm;

    wm.setAPCallback([](WiFiManager* w){
        Serial.println("Entered AP mode.");
        setBrightness(1);
        setRingRgb(255, 245, 0); // Yellow to indicate AP mode
    });

    wm.setSaveConfigCallback([](){
        showWifiSuccessFeedback();
        // we wait for 30sec after saving but before turning off the AP
        // to let the user read the confirmation message on their phone.
        // Otherwise, the AP would disappear immediately after saving, which can be confusing.
        Serial.println("WiFi saved. Keeping AP alive for 30s...");
        delay(30000);
        setRingRgb(0, 0, 0); // Off to indicate the process is complete and AP is going away
    });

    String customHead = WIFI_MANAGER_CUSTOM_HEAD;
    customHead.replace("%HOSTNAME%", hostname);
    wm.setCustomHeadElement(customHead.c_str());

    String apName = "Led'o'clock AP " + chipId;
    if (!wm.autoConnect(apName.c_str())) {
        Serial.println("Failed to connect and hit timeout");
        ESP.restart();
    }

    configureWiFiRoaming();

    Serial.println("Connected to WiFi. IP address: " + WiFi.localIP().toString());

    showWifiSuccessFeedback();

    // --- Preferences Initialization ---
    initPreferences();
    
    globalBrightness = loadBrightness();

    loadColorsFromFS();
    int savedColorIndex = loadColorModeIndex();
    String initialColor = "off"; 
    if (savedColorIndex < definedColorCount) {
        initialColor = definedColors[savedColorIndex].name;
    }
    applyColor(initialColor);

    loadSchedulesFromFS();
    loadTimezoneFromFS();

    Serial.println("Initialization complete.");

    // Restore the initial color based on EEPROM or schedule
    applyColor(initialColor);

    if (MDNS.begin(hostname.c_str())) {
        Serial.println("MDNS responder started with hostname: " + hostname);
    }

    // Time Sync with saved timezone
    configTzTime(currentTimezone.c_str(), "pool.ntp.org");

    initEndpoints();
}

void loop() {
    handleWebClient();

    // Check WiFi Reset Button
    static unsigned long buttonPressStartTime = 0;

    if (digitalRead(PIN_BUTTON) == LOW) {
        if (buttonPressStartTime == 0) {
            buttonPressStartTime = millis();
        } else if (millis() - buttonPressStartTime > 5000) {
            showFactoryResetFeedback();
            performFactoryReset();
        }
    } else {
        buttonPressStartTime = 0;
    }

    // Flag to track if we have applied the correct schedule after a reboot
    static bool initialTimeSyncDone = false;
    static unsigned long lastCheck = 0;

    if (millis() - lastCheck > 1000) {
        // If time is not synced yet, check if it just became available
        if (!initialTimeSyncDone) {
            time_t now = time(nullptr);
            struct tm* p_tm = localtime(&now);
            // If year is >= 100, the ESP has received the NTP time
            if (p_tm->tm_year >= 100) {
                Serial.println("Time synchronized via NTP.");
                Serial.println("Evaluating correct schedule...");
                
                initialTimeSyncDone = true;
                
                // Force the color calculation based on the new absolute time
                forceStateEvaluation();
            }
        }

        checkTimeEvents();
        updateLedRing();
        lastCheck = millis();
    }
}

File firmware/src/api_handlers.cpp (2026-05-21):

#include <Arduino.h>
#include <ArduinoJson.h>
#include <esp_mac.h>
#include <WebServer.h>
#include <WiFiManager.h>

#include "api_handlers.h"
#include "config.h"
#include "led_control.h"
#include "ota_service.h"
#include "storage.h"

extern const uint8_t index_html_start[] asm("_binary_src_web_index_html_start");
extern const uint8_t index_html_end[]   asm("_binary_src_web_index_html_end");

extern const uint8_t index_js_start[] asm("_binary_src_web_index_js_start");
extern const uint8_t index_js_end[]   asm("_binary_src_web_index_js_end");

extern const uint8_t configuration_html_start[] asm("_binary_src_web_configuration_html_start");
extern const uint8_t configuration_html_end[]   asm("_binary_src_web_configuration_html_end");

extern const uint8_t configuration_js_start[] asm("_binary_src_web_configuration_js_start");
extern const uint8_t configuration_js_end[]   asm("_binary_src_web_configuration_js_end");

extern const uint8_t common_css_start[]  asm("_binary_src_web_common_css_start");
extern const uint8_t common_css_end[]    asm("_binary_src_web_common_css_end");

extern const uint8_t common_js_start[]  asm("_binary_src_web_common_js_start");
extern const uint8_t common_js_end[]    asm("_binary_src_web_common_js_end");

static WebServer server(80);

/**
 * Helper to get a truly unique Chip ID based on full MAC
 */
String getUniqueChipId() {
    uint8_t mac[6];
    if (esp_read_mac(mac, ESP_MAC_WIFI_STA) != ESP_OK) {
        return "000000000000";
    }
    char chipIdBuf[13];
    snprintf(chipIdBuf, sizeof(chipIdBuf), "%02x%02x%02x%02x%02x%02x", 
             mac[0], mac[1], mac[2], mac[3], mac[4], mac[5]);
             
    return String(chipIdBuf);
}

/**
 * Trims trailing null or 0xFF bytes from embedded binary data
 */
size_t getCleanSize(const uint8_t* start, const uint8_t* end) {
    const char* data = (const char*)start;
    size_t size = end - start;
    while (size > 0 && (data[size - 1] == 0x00 || (uint8_t)data[size - 1] == 0xFF)) {
        size--;
    }
    return size;
}

/**
 * Serves a static file directly from Flash with caching headers
 */
void serveStaticEmbed(const uint8_t* start, const uint8_t* end, const char* contentType) {
    size_t size = getCleanSize(start, end);
    String etag = "\"" + String(FIRMWARE_VERSION) + "\"";

    if (server.hasHeader("If-None-Match") && server.header("If-None-Match") == etag) {
        server.sendHeader("Cache-Control", "public, max-age=86400");
        server.sendHeader("ETag", etag);
        server.send(304);
        return;
    }

    server.sendHeader("Cache-Control", "public, max-age=86400");
    server.sendHeader("ETag", etag);
    server.send_P(200, contentType, (const char*)start, size);
}

/**
 * Returns a clean String from embedded Flash data (for placeholders replacement)
 */
String getEmbedString(const uint8_t* start, const uint8_t* end) {
    size_t size = getCleanSize(start, end);
    String s = "";
    s.concat((const char*)start, size);
    return s;
}

void handleRoot() {
    Serial.println("handleRoot");

    String chipId = getUniqueChipId();
    String hostname = "ledoclock-" + chipId;
    String mac = WiFi.macAddress();
    String ip = WiFi.localIP().toString();

    String etag = "\"" + String(FIRMWARE_VERSION) + "-" + ip + "\"";
    if (server.hasHeader("If-None-Match") && server.header("If-None-Match") == etag) {
        server.sendHeader("Cache-Control", "no-cache");
        server.sendHeader("ETag", etag);
        server.send(304);
        return;
    }

    // load index.html from Flash and replace placeholders
    String html = getEmbedString(index_html_start, index_html_end);
    if (html.length() == 0) {
        Serial.println("Error: Could not load index.html from Flash");
        server.send(500, "text/plain", "Internal Server Error");
        return;
    }

    html.replace("%HOSTNAME%", hostname);
    html.replace("%MAC%", mac);
    html.replace("%IP%", ip);
    html.replace("%VERSION%", String(FIRMWARE_VERSION));

    server.sendHeader("Cache-Control", "no-cache");
    server.sendHeader("ETag", etag);
    server.send(200, "text/html", html);
}


void handlePing() {
    Serial.println("handlePing");
    server.send(200, "application/json", "{\"status\":\"pong\"}");
}

void handleConfigure() {
    Serial.println("handleConfigure");
    serveStaticEmbed(configuration_html_start, configuration_html_end, "text/html");
}

/**
 * Clears WiFi credentials and restarts the device
 * to force the configuration portal on next boot.
 */
void handleResetWifi() {
    Serial.println("handleResetWifi");
    server.send(200, "application/json", "{\"status\":\"WiFi settings cleared. Unplug and plug the device to restart in Access Point mode.\"}");
    // Give the server time to send the response
    delay(2000);

    WiFiManager wm;
    wm.resetSettings();
    ESP.restart();
}

/**
 * Clears all configurations, WiFi credentials and restarts the device
 * to force the configuration portal on next boot.
 */
void handleResetAll() {
    Serial.println("handleResetAll");
    server.send(200, "application/json", "{\"status\":\"Settings cleared. Unplug and plug the device to restart in Access Point mode.\"}");
    // Give the server time to send the response
    delay(1000);

    showFactoryResetFeedback();
    performFactoryReset();
}
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

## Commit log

2026-04-11 chore(release): 0.1.0 [skip ci]
    # [0.1.0](https://github.com/denouche/led-o-clock/compare/0.0.1...0.1.0) (2026-04-11)
    ### Features
    * add ci workflows ([776b9b9](https://github.com/denouche/led-o-clock/commit/776b9b9ad46168cb7f1f9bd4b5ebaec1965b2cb0))
2026-04-11 chore(release): 0.1.1 [skip ci]
    ## [0.1.1](https://github.com/denouche/led-o-clock/compare/0.1.0...0.1.1) (2026-04-11)
    ### Bug Fixes
    * **firmware:** improve success toast when saving configuration ([ac17b20](https://github.com/denouche/led-o-clock/commit/ac17b20a670e8e572bbc93c68a41e2f8bcd23e4a))
    * fix release firmware publish ([7784a4f](https://github.com/denouche/led-o-clock/commit/7784a4fffaed6dbe78a8b9fdbee2c75096bf966c))
2026-04-11 chore(release): 0.2.0 [skip ci]
    # [0.2.0](https://github.com/denouche/led-o-clock/compare/0.1.1...0.2.0) (2026-04-11)
    * **firmware:** add OTA update support ([87618de](https://github.com/denouche/led-o-clock/commit/87618deee0467314c9d811fd38103e1c16b057e7))
    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
2026-04-11 chore(release): 0.2.1 [skip ci]
    ## [0.2.1](https://github.com/denouche/led-o-clock/compare/0.2.0...0.2.1) (2026-04-11)
    * **firmware:** add missing firmware upgrade documentation on index ([eac0821](https://github.com/denouche/led-o-clock/commit/eac082140b3520e5f0013a624b8bb06c9eb9eabd))
    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
2026-04-11 feat(enclosure): add enclosure files
    [ledoclock-box bottom.stl, ledoclock-lid.stl, ledoclock-ring retainer.stl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]
2026-04-11 chore(release): 0.3.0 [skip ci]
    # [0.3.0](https://github.com/denouche/led-o-clock/compare/0.2.1...0.3.0) (2026-04-11)
    * **enclosure:** add enclosure files ([ff69254](https://github.com/denouche/led-o-clock/commit/ff6925458fe482433d2bfd948a1ecf59863dcd38))
    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
2026-04-12 fix(firmware): factory reset feedback is now a red blink 5 times (#1)
    [api_handlers.cpp, main.cpp]
2026-04-12 chore(release): 0.3.1 [skip ci]
    ## [0.3.1](https://github.com/denouche/led-o-clock/compare/0.3.0...0.3.1) (2026-04-12)
    * **firmware:** factory reset feedback is now a red blink 5 times ([#1](https://github.com/denouche/led-o-clock/issues/1)) ([de2a2db](https://github.com/denouche/led-o-clock/commit/de2a2dbc27fe11c1482be1cc582173bf9838cc6d))
    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
2026-04-12 chore(release): 0.4.0 [skip ci]
    # [0.4.0](https://github.com/denouche/led-o-clock/compare/0.3.1...0.4.0) (2026-04-12)
    * **firmware:** allow to customize brightness for each schedule ([#3](https://github.com/denouche/led-o-clock/issues/3)) ([9e97505](https://github.com/denouche/led-o-clock/commit/9e97505a7ca96110615698fc4b5895fbce906067))
    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
2026-04-12 chore(release): 0.5.0 [skip ci]
    # [0.5.0](https://github.com/denouche/led-o-clock/compare/0.4.0...0.5.0) (2026-04-12)
    * change firmware upgrade endpoint from GET to POST with toast feedback ([#4](https://github.com/denouche/led-o-clock/issues/4)) ([71c531c](https://github.com/denouche/led-o-clock/commit/71c531c76bc877f158fbf49b6a1576a7a53bc879))
    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
2026-04-12 feat(firmware): display current and available firmware versions on web UI (#5)
2026-04-12 chore(release): 0.6.0 [skip ci]
    # [0.6.0](https://github.com/denouche/led-o-clock/compare/0.5.0...0.6.0) (2026-04-12)
    * **firmware:** display current and available firmware versions on web UI ([#5](https://github.com/denouche/led-o-clock/issues/5)) ([de0d7cf](https://github.com/denouche/led-o-clock/commit/de0d7cf7bd49da8f819df5712bd062cbf80a3978))
    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
2026-04-29 feat: add pcb folder and work on readme
    [BOM-led-o-clock.csv, led-o-clock.kicad_pcb, led-o-clock.kicad_sch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]
2026-04-29 chore(release): 0.7.0 [skip ci]
    # [0.7.0](https://github.com/denouche/led-o-clock/compare/0.6.0...0.7.0) (2026-04-29)
    * add pcb folder and work on readme ([51abcd6](https://github.com/denouche/led-o-clock/commit/51abcd60a1240a7f589b55eeadc327e77937034b))
    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
2026-04-29 docs: work on enclosure readme
2026-04-29 chore(release): 1.0.0 [skip ci]
    # 1.0.0 (2026-04-29)
    * **firmware:** fix documentation ([69edb70](https://github.com/denouche/led-o-clock/commit/69edb7068c953dc65c9f04d9776cdc7684711e32))
    * **firmware:** improve success toast when saving configuration ([ac17b20](https://github.com/denouche/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
2026-04-29 fix(pcb): move jst connector on the top (#6)
    [led-o-clock.kicad_pcb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]
2026-04-29 chore(release): 1.1.0 [skip ci]
    # [1.1.0](https://github.com/denouche/led-o-clock/compare/firmware-1.0.0...firmware-1.1.0) (2026-04-29)
    * **pcb:** move jst connector on the top ([#6](https://github.com/denouche/led-o-clock/issues/6)) ([a4a3ec3](https://github.com/denouche/led-o-clock/commit/a4a3ec3f5f545fc882d85de9f8cf33023da9cf9b))
    * **firmware:** use gh pages manifest for OTA update ([#7](https://github.com/denouche/led-o-clock/issues/7)) ([9efd22f](https://github.com/denouche/led-o-clock/commit/9efd22f0976dd2a50e7f2274a3ea8f6e5961b008))
    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
2026-05-07 fix(pcb): improve button placement and add QR code
    [led-o-clock.kicad_pcb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]
2026-05-19 feat(pcb): work on v3.2
    [BOM-led-o-clock.csv, led-o-clock.kicad_pcb, led-o-clock.kicad_sch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]
2026-05-19 feat(enclosure): work on v3.1 enclosure
    [ledoclock-box bottom v3.0.stl, ledoclock-box bottom v3.1.stl, ledoclock-lid.stl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]
2026-05-19 docs(pcb): add work in progress v3.2 info
2026-05-21 chore(release): 1.2.0 [skip ci]
    # [1.2.0](https://github.com/denouche/led-o-clock/compare/firmware-1.1.0...firmware-1.2.0) (2026-05-21)
    * **pcb:** improve button placement and add QR code ([9fd4abb](https://github.com/denouche/led-o-clock/commit/9fd4abb37743e466d26927f49193d1b6cf61663b))
    * **enclosure:** work on v3.1 enclosure ([44e2d0d](https://github.com/denouche/led-o-clock/commit/44e2d0d0b37f5188ccae702cb5005594614ab368))
    * **firmware:** add GET /set_leds_on endpoint ([#8](https://github.com/denouche/led-o-clock/issues/8)) ([9e0ffce](https://github.com/denouche/led-o-clock/commit/9e0ffcedce582659c4645045b0127e3a8afb4af7))
    * **pcb:** work on v3.2 ([9e711f4](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
